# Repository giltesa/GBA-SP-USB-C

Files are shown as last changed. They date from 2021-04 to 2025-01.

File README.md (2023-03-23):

# Game Boy Advance SP USB-C & Audio Kit

This board allows to replace the original EXT2 connector and keep both original features: You can charge the GBASP by USB-C and **connect to your headphones to hear the games**!

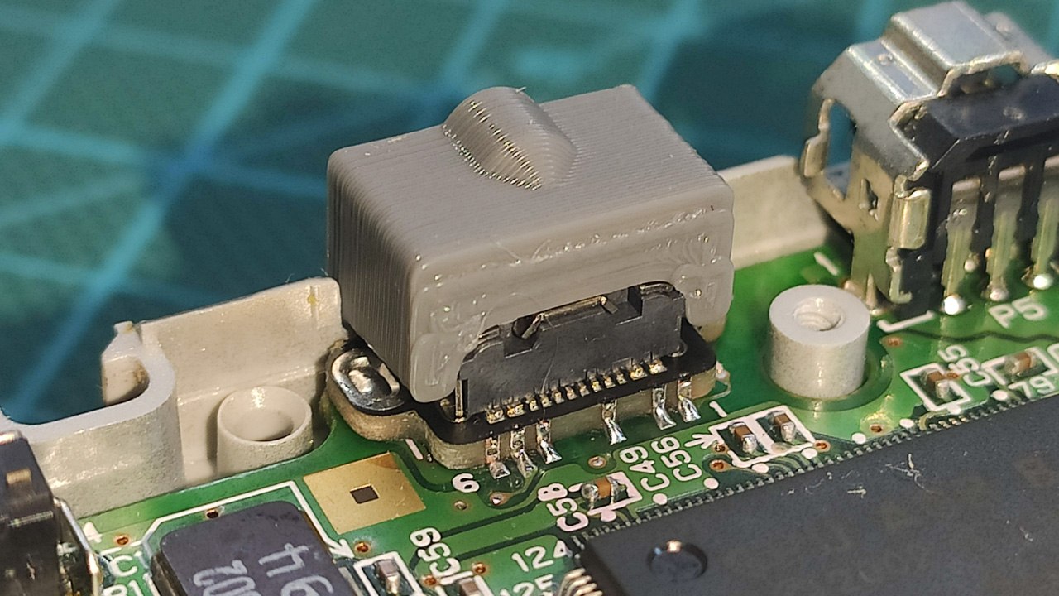
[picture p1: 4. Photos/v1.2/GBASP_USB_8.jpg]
GBASP

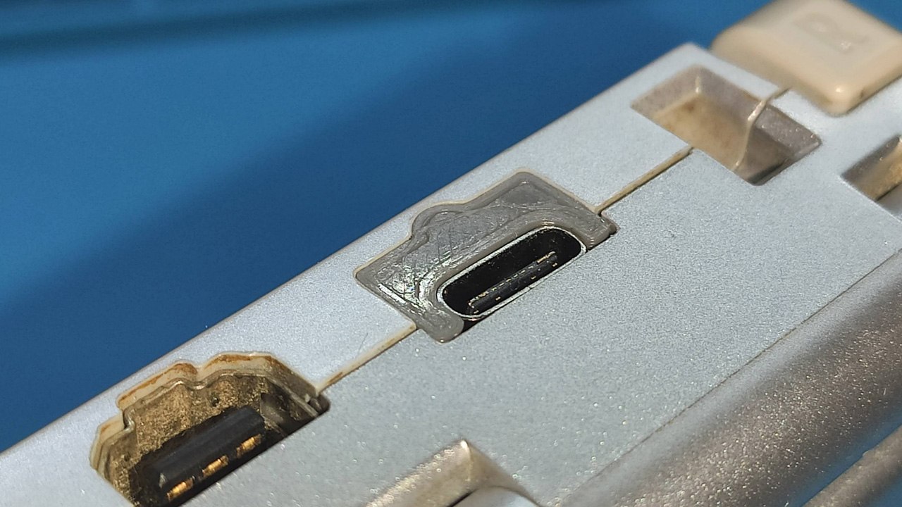
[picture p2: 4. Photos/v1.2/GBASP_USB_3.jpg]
GBASP

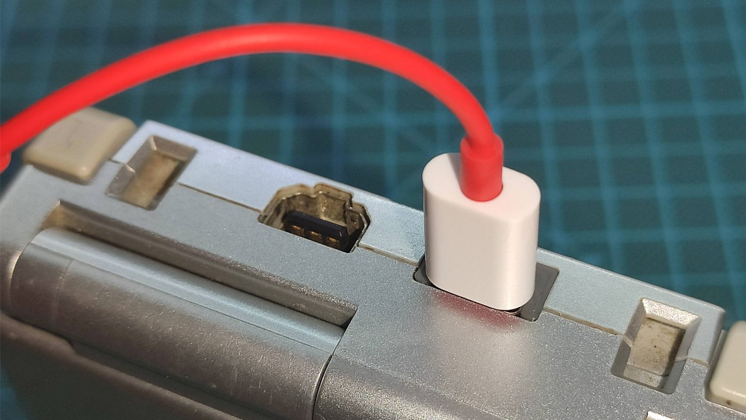
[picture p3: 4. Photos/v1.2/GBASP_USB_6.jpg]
GBASP


## Youtube:

Game Boy Advance SP USB-C & Audio Kit (Installation)

GBASP (https://www.youtube.com/watch?v=e_Pdkdgis8E)

## Would you like it?

https://shop.giltesa.com/product/game-boy-advance-sp-usb-c-kit/

https://shop.giltesa.com/product/game-boy-advance-sp-usb-c-kit-centered/

## More

- [giltesa.com](https://giltesa.com "giltesa.com")
- [twitter.com](https://twitter.com/giltesa/status/1503669454852481024 "twitter.com")

## Thanks

Thanks to these makers for publishing the information about the pinout and their experiences, it helped me to make this board:

[ishoug](https://www.youtube.com/watch?v=KATEinUUWz0 "ishoug")

[666Gothicgirl](https://www.youtube.com/watch?v=5_2sGFCsaPw "666Gothicgirl")

## License

This project is licensed under a **Creative Commons** license:
**[Attribution-NonCommercial-ShareAlike 4.0 International (CC BY-NC-SA 4.0) ](https://creativecommons.org/licenses/by-nc-sa/4.0/)**

Check the [LICENSE.md](LICENSE.md) for more information.

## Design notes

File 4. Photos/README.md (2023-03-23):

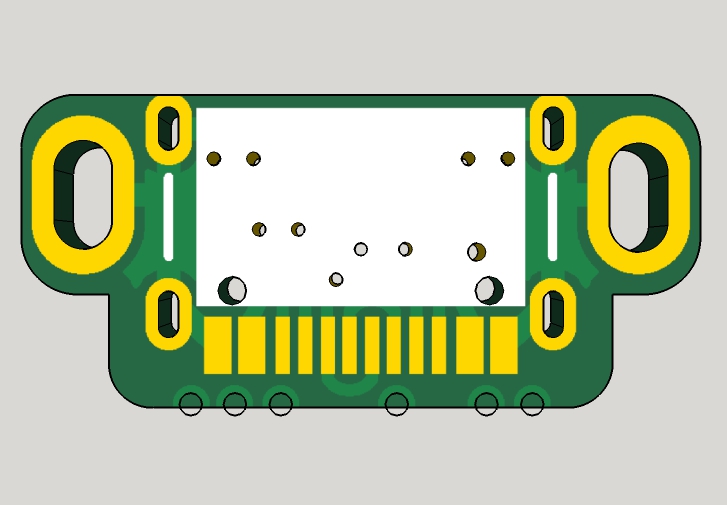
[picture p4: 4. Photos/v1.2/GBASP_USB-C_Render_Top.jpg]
GBASP

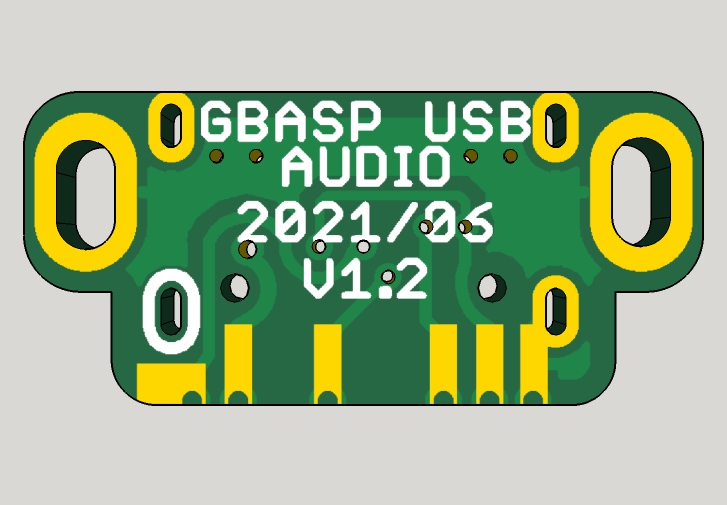
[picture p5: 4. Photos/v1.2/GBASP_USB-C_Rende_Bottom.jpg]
GBASP

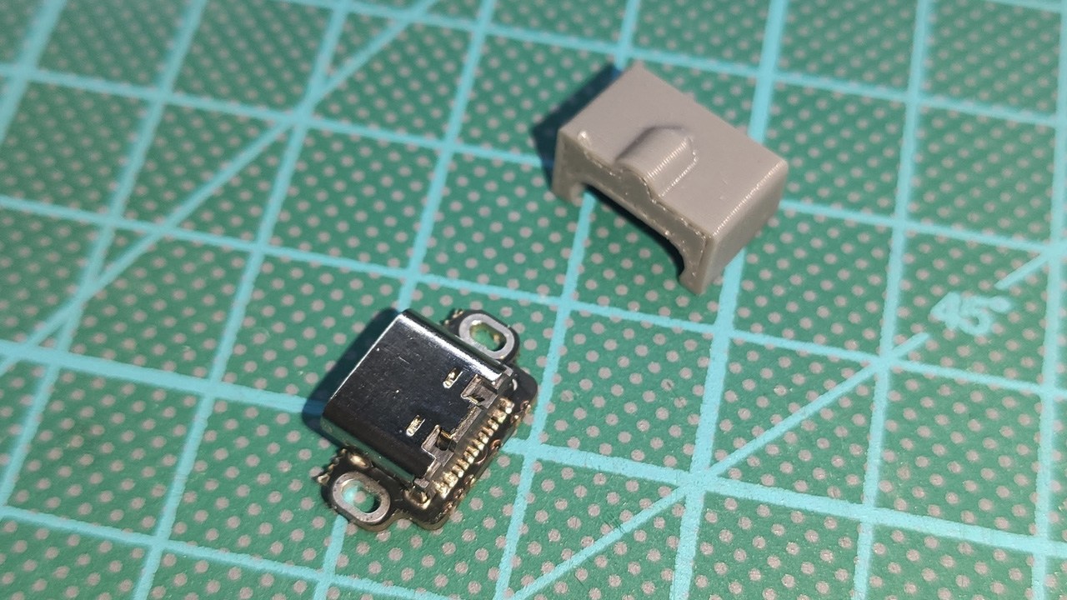
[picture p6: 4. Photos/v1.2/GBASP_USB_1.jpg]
GBASP

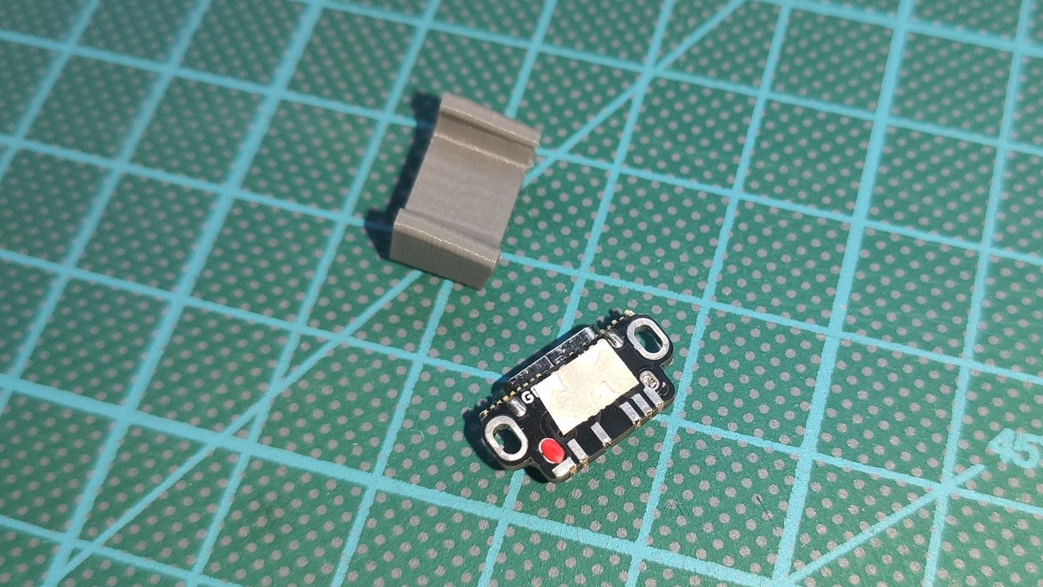
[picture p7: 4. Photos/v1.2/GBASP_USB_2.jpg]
GBASP

GBASP
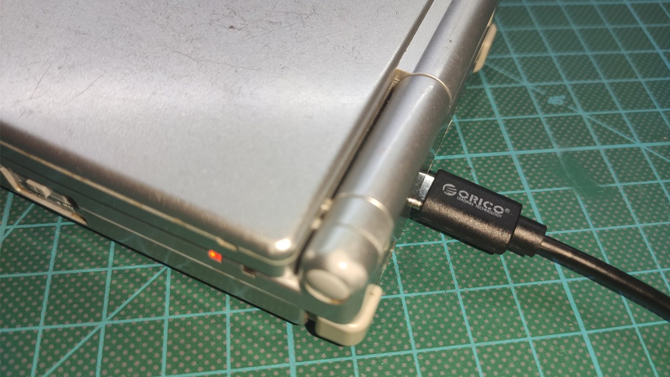
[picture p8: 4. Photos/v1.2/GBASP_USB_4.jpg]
GBASP

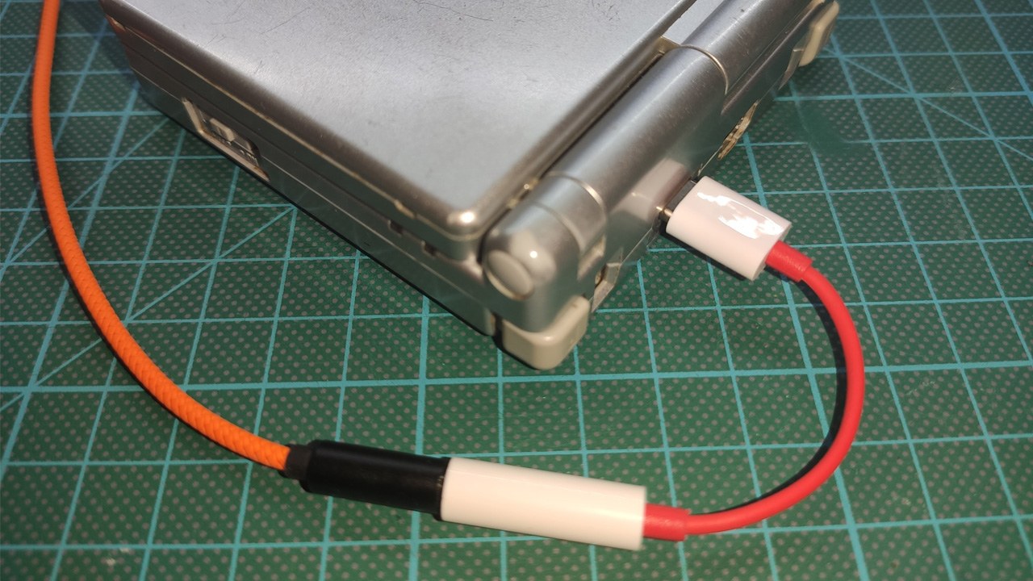
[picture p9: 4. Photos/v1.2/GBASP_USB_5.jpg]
GBASP

GBASP
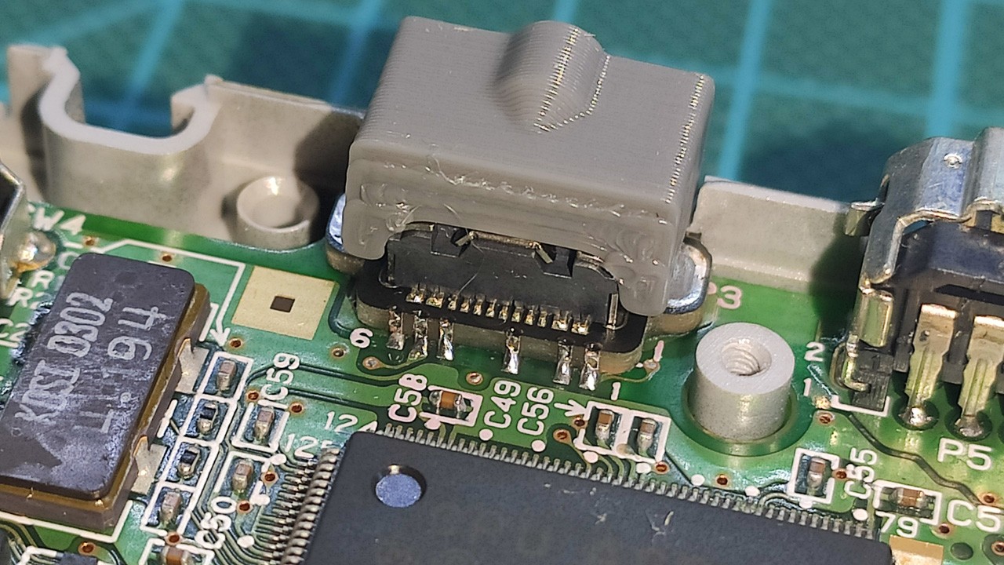
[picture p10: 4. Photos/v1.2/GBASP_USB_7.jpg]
GBASP

GBASP
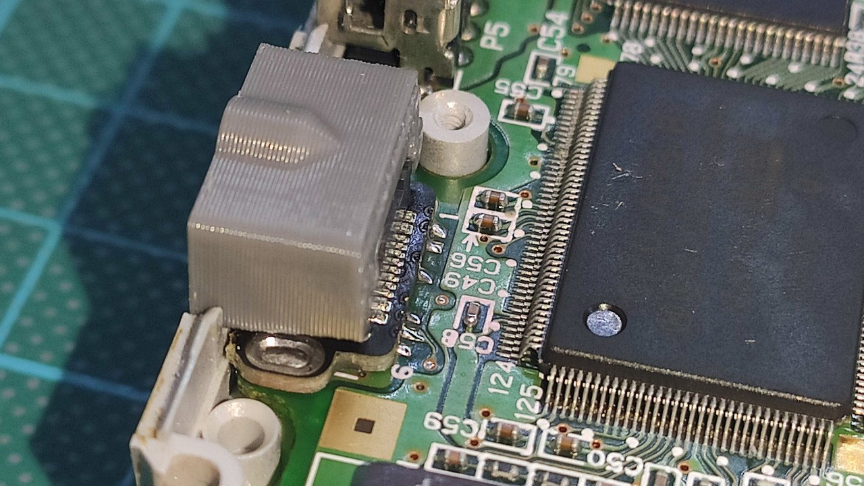
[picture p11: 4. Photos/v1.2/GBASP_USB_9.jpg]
GBASP


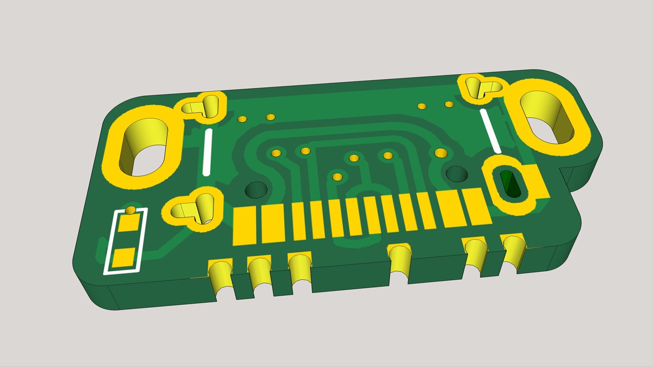
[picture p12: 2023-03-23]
2. Renders, 3D models/gbasp-v2.jpg

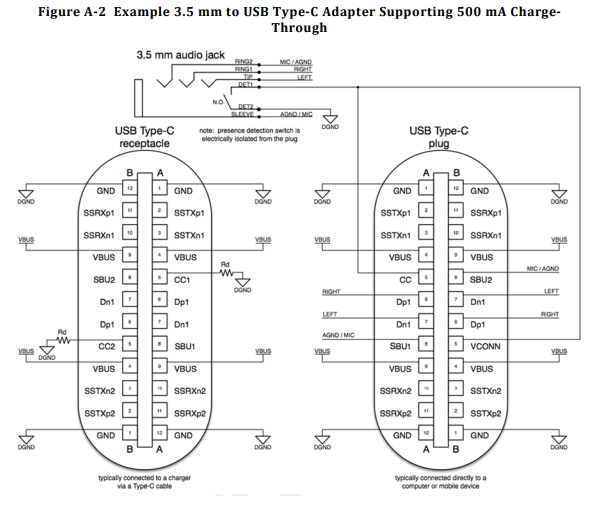
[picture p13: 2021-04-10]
3. Documentation/Datasheet/3mm-to-USB-Type-C-adapter-with-charging.png

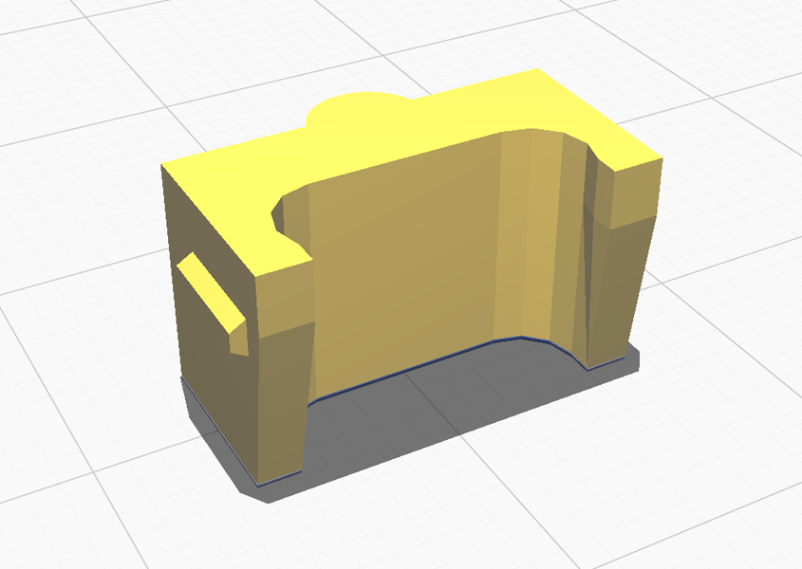
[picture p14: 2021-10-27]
2. Renders, 3D models/Plastic Cap/1. Half/v15/GBA-SP-CAP.png

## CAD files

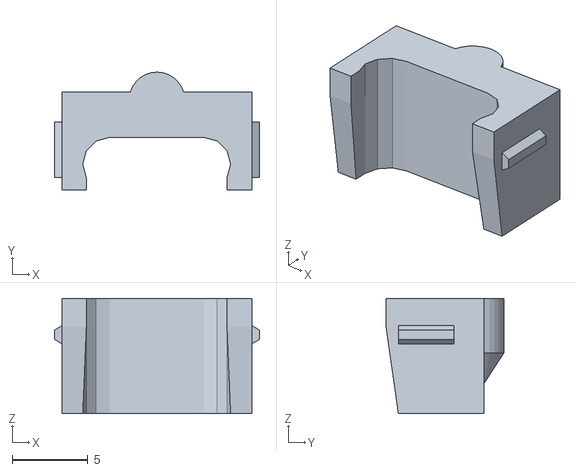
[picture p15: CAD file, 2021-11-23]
2. Renders, 3D models/Plastic Cap/1. Half/v15/GBA-SP-CAP.stl
13.5 x 7.76 x 7.60

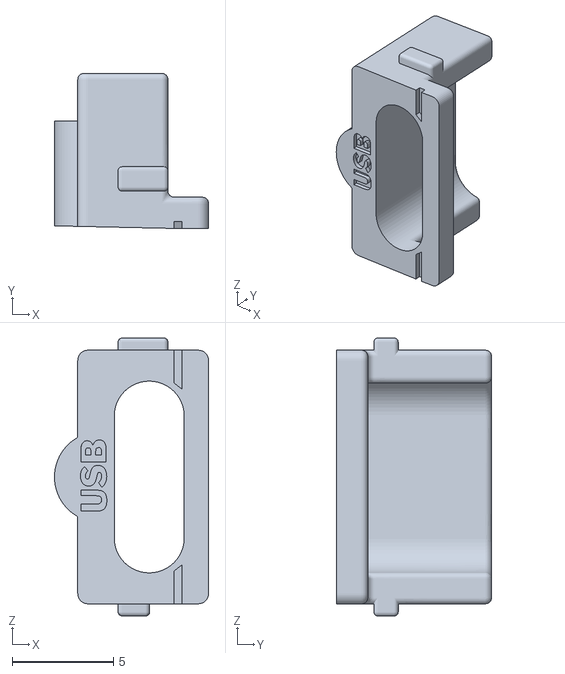
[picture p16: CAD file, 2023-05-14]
2. Renders, 3D models/Plastic Cap/2. Centered/v30/GBASP_CAP_v30.stl
7.60 x 7.65 x 13.7

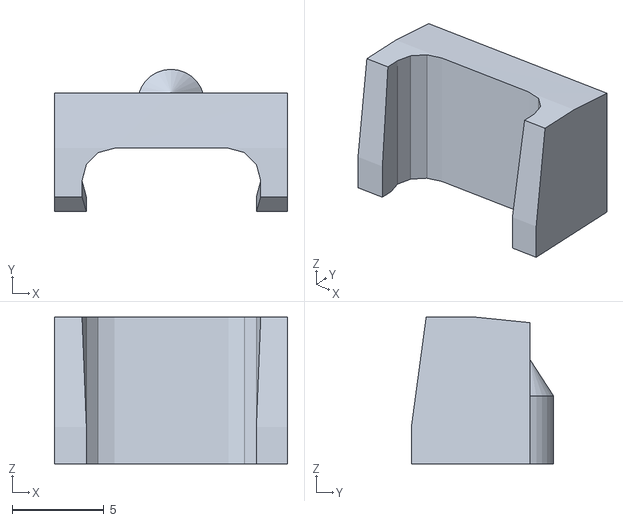
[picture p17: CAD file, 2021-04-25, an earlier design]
2. Renders, 3D models/Plastic Cap/1. Half/v13/GBA-SP-CAP.stl
12.7 x 7.76 x 8.00

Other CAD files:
2. Renders, 3D models/GBA SP 1.skp
2. Renders, 3D models/GBA SP 2.skp
2. Renders, 3D models/GBA-SP-CAP - Black.skp
2. Renders, 3D models/GBA-SP-CAP - Blue.skp
2. Renders, 3D models/Plastic Cap/1. Half/v13/GBA-SP-CAP.skp
2. Renders, 3D models/Plastic Cap/1. Half/v15/GBA-SP-CAP.skp
2. Renders, 3D models/Plastic Cap/2. Centered/v30/GBA-SP-CAP.skp
2. Renders, 3D models/Plastic Cap/2. Centered/v30/GBASP_CAP v30.f3d
2. Renders, 3D models/gbasp-v2.skp

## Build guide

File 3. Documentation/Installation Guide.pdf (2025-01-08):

# USB-C KIT For

# Game Boy Advance SP Nintendo DS

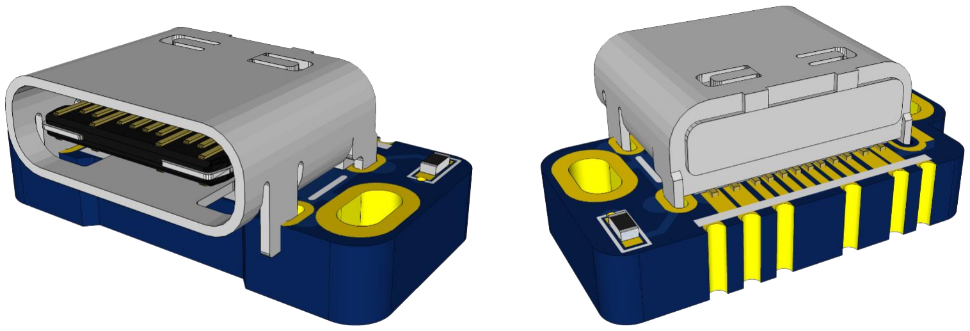
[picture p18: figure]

### PRODUCT v1.6+

HTTPS://SHOP.GILTESA.COM/PRODUCT/GAME-BOY-ADVANCE-SP-USB-C-KIT-CENTERED

# PLEASE READ THROUGH THESE INSTRUCTIONS

ENTIRELY BEFORE ATTEMPTING TO INSTALL.

# WARNING: IF YOU ARE NOT COMFORTABLE WITH SOLDERING, OR PERFORMING ANY STEP IN THIS

GUIDE, DO NOT PERFORM THE INSTALL YOURSELF.

# FIND SOMEONE WHO IS COMFORTABLE TO DO IT FOR

YOU.

INDEX

# Description

The Game Boy Advance SP: USB-C Kit allows to charge the battery by USB-C cable or connect headphones with USB-C or by jack adapter to USB-C in your Game Boy Advance SP (Also compatible with Nintendo DS, you can see some details of the installation at the end of the document.)
The USB-C specification has two ways of audio connections. Be sure your headphones or jack adapter use the first one because otherwise you will not be able to hear anything.
- COMPATIBLE: The legacy one that use some extra pines of the USB-C to take out the analog audio and where you can connect normal headphones or jack adapter.
- NOT COMPATIBLE: The advanced one where the headphones include a DAC (Digital to Analogue Converter) and needs energy from the USB connector to manage the electronic components inside the headphone’s connector.

There are two versions of this board, both with the same features except for the thickness of the board. The first one has 1.2mm thickness, and the USB-C connector is level with the joining of both parts of the GBASP shell. The second version has a 2.4mm thickness the USB-C connector is almost in the centre of the hole.

The plastic cap to cover the hole may change between both versions, check the shop product description for more details.

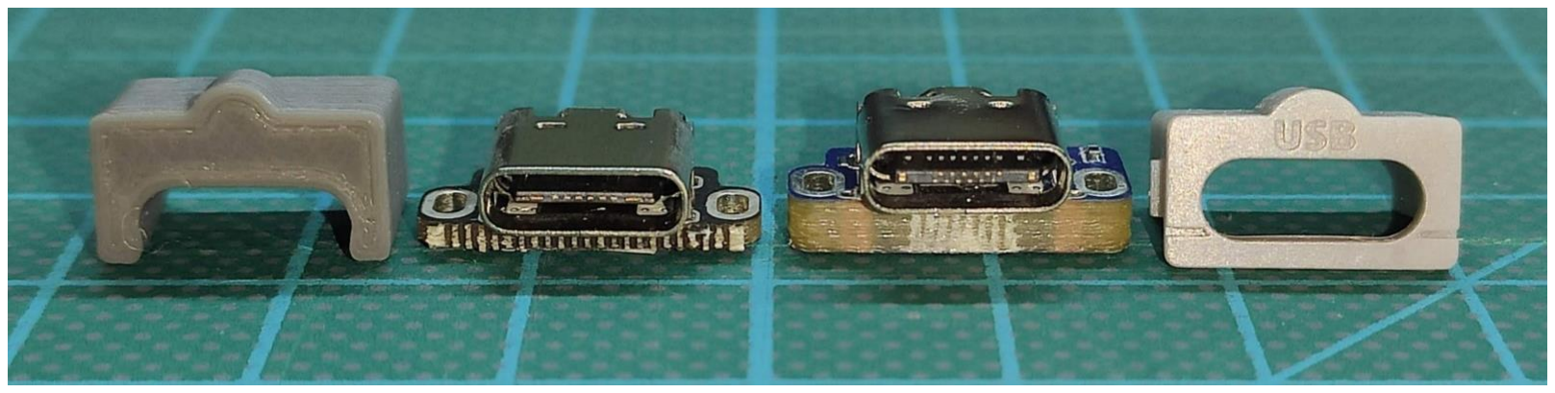
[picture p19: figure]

Comparison between the two versions: Left 1.2mm, right 2.4mm

# FEATURES

- New castellated holes (pads): It has never been so easy to solder it. (Link) (https://shop.giltesa.com/wp-content/uploads/2022/09/gbasp-usb-c-kit-installation.webp)
- Plastic cap made by 3D printer or resin 3D printer.
- Charging your Game Boy Advance SP by USB-C, compatible with:
- USB power banks
- USB-A chargers
- USB-C chargers *
- USB-C PD chargers (normal speed, not fast) *
- USB-A to USB-C cables
- USB-C to USB-C cables *
- Playing the sound using a USB-C headphones or USB-C adapter to Jack 3.5mm.

* This feature has been recently added but has a limitation. Before USB-C to USB-C cables were not compatible and they didn’t charge the GBA SP. They can be used now, but they work only connected in one side. It means when you connect the USB-C cable face up will charge correctly the battery and the orange led will turn on, but when you connect face down will not do anything.

(Supporting double side connecting disable the audio of the speaker. So, this is the best option to keep the audio works and makes the USB-C to USB-C cables/chargers compatible.

# INCLUDED

- 1 board (1.2mm or 2.4 mm thickness depending on the choose version)
- 1 plastic cap to cover the hole.

# Recommended / REQUIRED (NOT INCLUDED)

- Tri-wing and phillips screwdriver
- Tweezers
- Cutting plier
- Kapton tape
- Soldering iron
- Tin
- Flux
- Desoldering pump
- Desoldering mesh
- Isopropyl alcohol

# Board details

This tiny board has eight pads in about 1cm²
surface, which means it requires high soldering skills. The following explains what each pad is for.

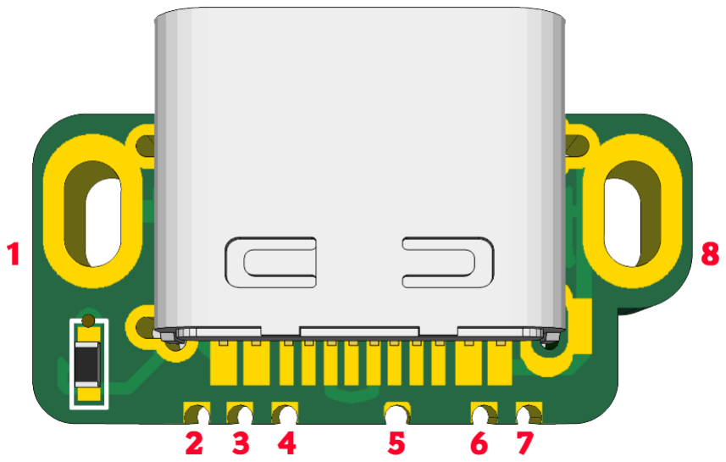
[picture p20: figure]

Starting from the left to the right:

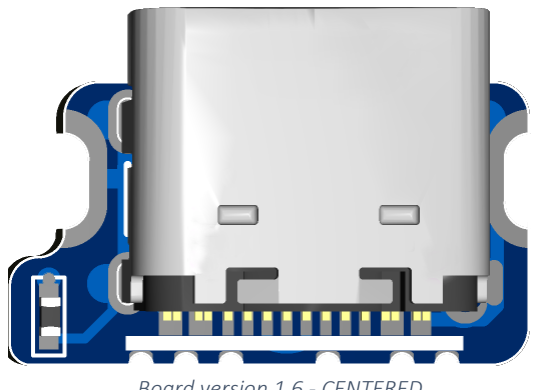
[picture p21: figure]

1. SHIELD *: | The shield pad, also as ground pad.
2. GND: | The ground pad.
3. SDN: | Shutdown pad to disable the speaker when the
| headphones are connected.
4. AUDIO GND: | The ground audio line.
5. AUDIO R: | The right audio line.
6. VCC: | The 5V line from the USB-C.
7. AUDIO L: | The left audio line.
8. SHIELD *: | The shield pad, also as ground pad.

* These two pads hold the board to the GBA SP motherboard, make sure to solder them well to hold the board properly.

2023-01: v1.6: The pads 1 and 8, called SHIELD, have been modified to facilitate installation. Now it is much easier to install, and since soldering can be done more easily, it is more robust, as previously, when these pads were closed, the soldering could be incorrectly applied.

Board version 1.6 - CENTERED

# INSTALLATION STEPS

## Pre installation Steps

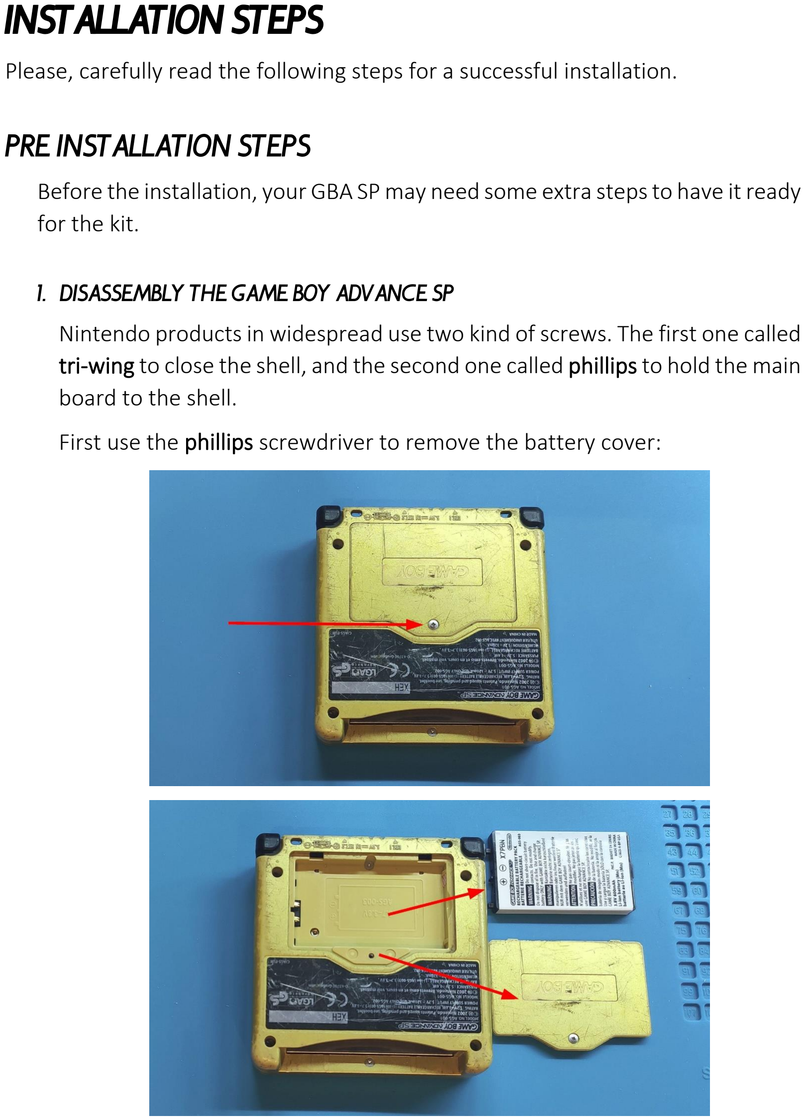
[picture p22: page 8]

Please, carefully read the following steps for a successful installation.

Before the installation, your GBA SP may need some extra steps to have it ready for the kit.

1. Disassembly the Game Boy ADVANCE SP

Nintendo products in widespread use two kind of screws. The first one called tri-wing to close the shell, and the second one called phillips to hold the main board to the shell.

First use the phillips screwdriver to remove the battery cover:

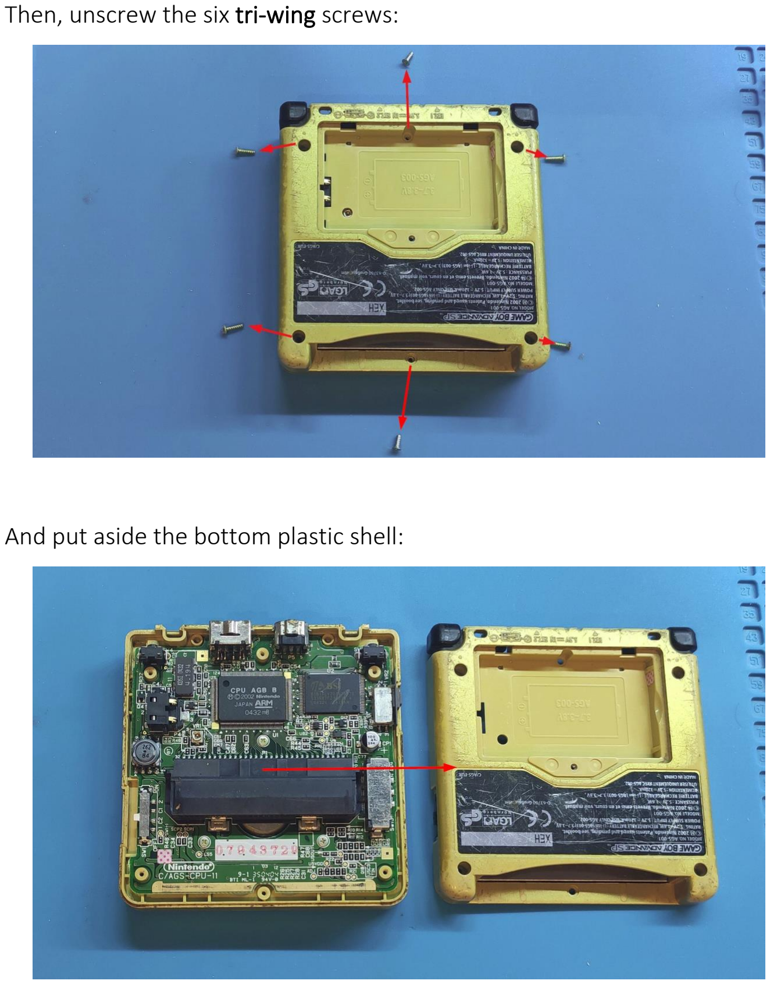
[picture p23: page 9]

Then, unscrew the six tri-wing screws:

And put aside the bottom plastic shell:

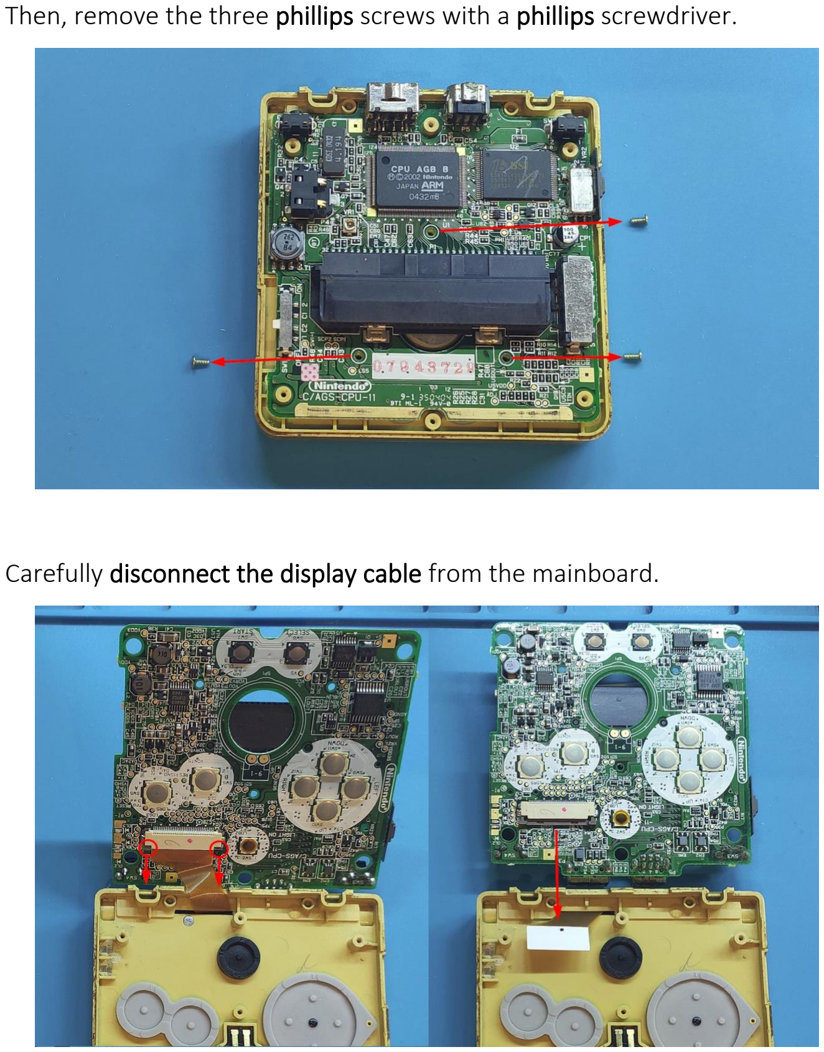
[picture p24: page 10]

Then, remove the three phillips screws with a phillips screwdriver.

Carefully disconnect the display cable from the mainboard.

As last step, the volume switch cover can be removed, but do not force it as it may be held tightly.

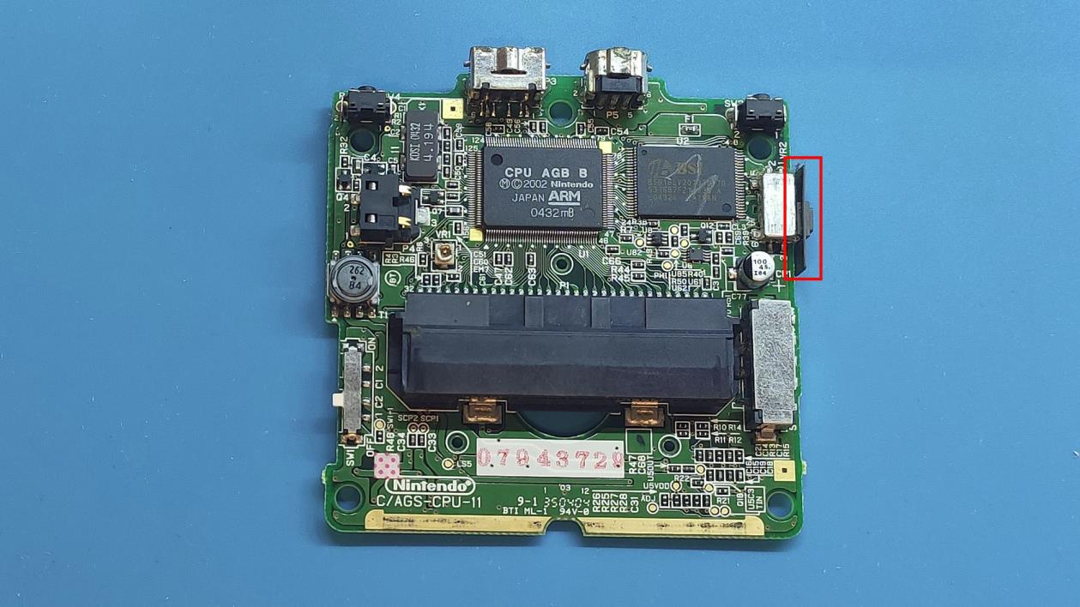
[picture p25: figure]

2. Cleaning the mainboard

Use isopropyl alcohol to clean the board. Since the board was made in 2002, the board may be full of dust. All this dirt can be cleaned with alcohol.

## installation Steps

1. Protect the nearest components

Use Kapton tape to protect and avoid any damage to the electronic components that are next to the connector.

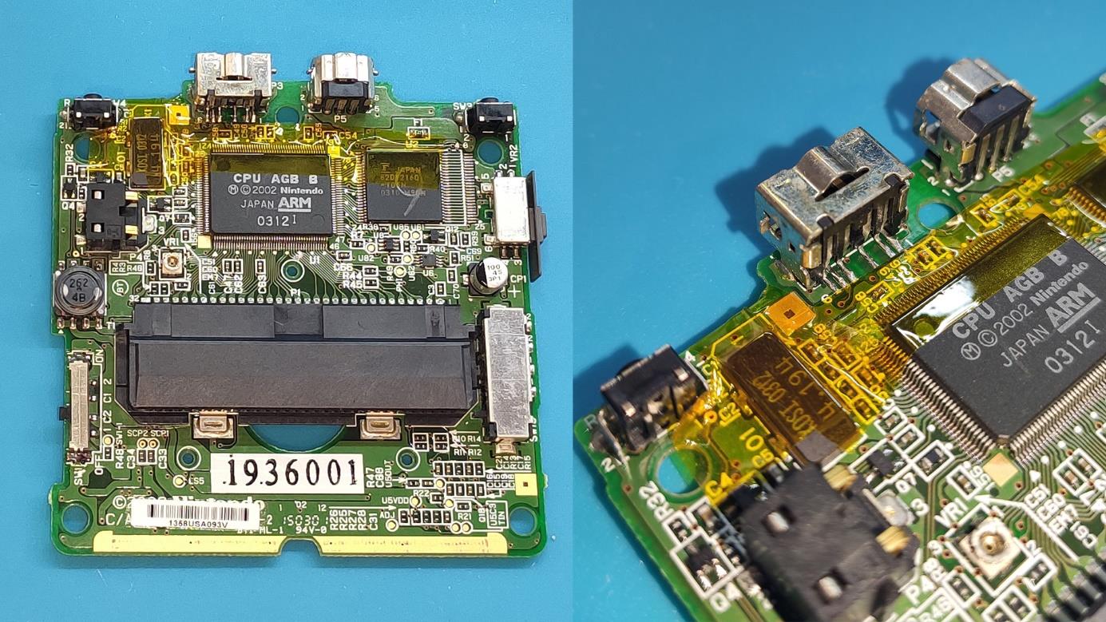
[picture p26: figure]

2. Remove unnecessary components

This kit only requires removing the EXT.2 connector. However, it has many legs, and it may be hard to remove. Following the next steps should help to do it.

If you have an air solder station, you can remove it easily, but protect perfect the nearest places with Kapton tape or something may be burn.

Otherwise, the recommendation is using a desoldering pump which will help to remove the tin from the shield pads.

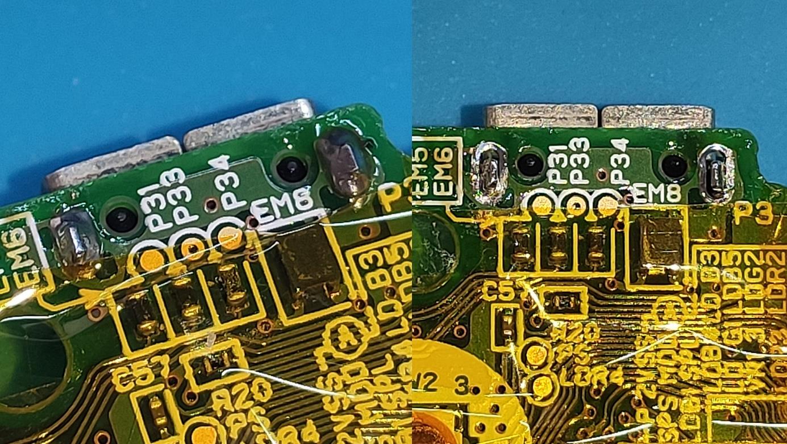
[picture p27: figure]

Left before, right after
After that, with the solder iron is possible to heat the remaining six legs at the same time and remove the connector. Some flux will help to desolder it.

BE INCREDIBLY CAREFUL WHEN REMOVING THE CONNECTOR. THE COPPER PADS, WHERE THE CONNECTOR IS SOLDERED, ARE EXTREMELY FRAGILE AND CAN PEEL OFF.

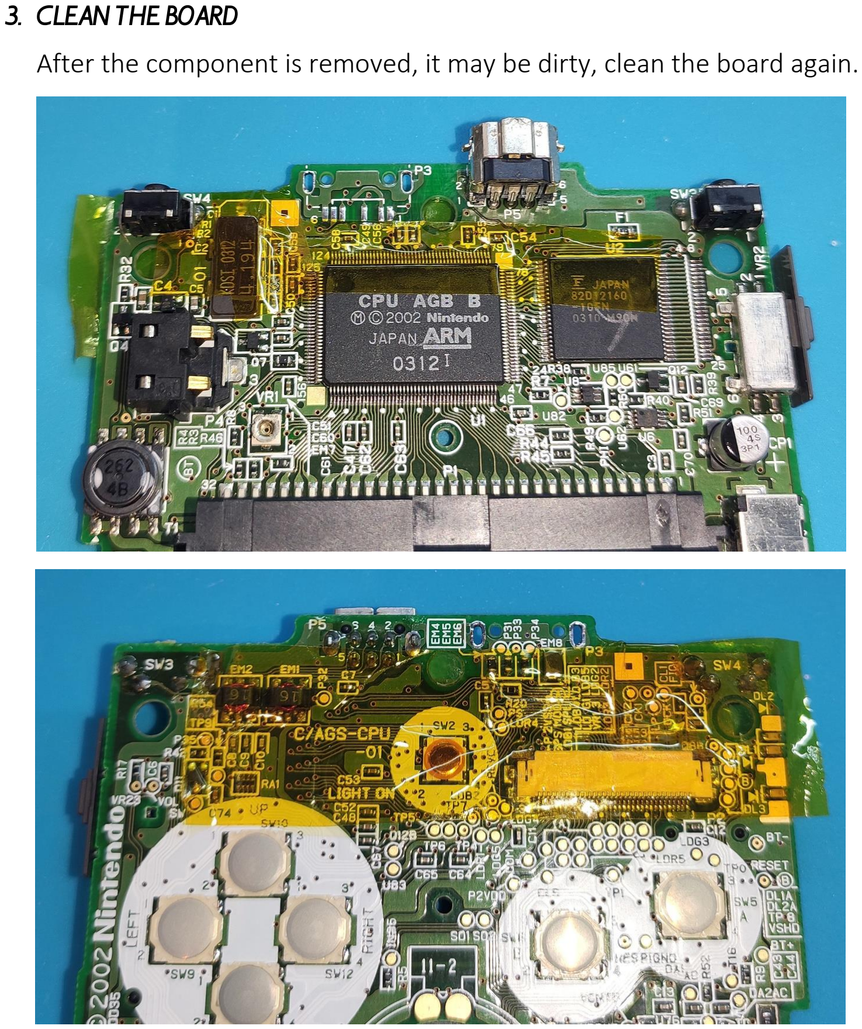
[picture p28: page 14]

3. Clean the board

After the component is removed, it may be dirty, clean the board again.

4. Installation of the USB-C board

The easier way to centre the board on the mainboard is when the mainboard is screw on the GBA SP shell, so, you can put it back (the video cable doesn’t need to be connected)

Once the mainboard is in the shell, you can place the board on the place where the original connector was. The board also must be touching the back of the plastic shell.

Please, see below video to understand how to do it:

https://www.youtube.com/watch?v=PKm9SWTC8MQ

At this point, you can put the plastic lid and check everything matches correctly.

After the 6 pads are correctly soldered, remove the mainboard from the plastic shell and finish the installation soldering the 2 big pads that will hold strong the board to the mainboard.

Be sure you solder it well and both pads are joined with the tin, otherwise the connector may move and damage the 6 weak pads.

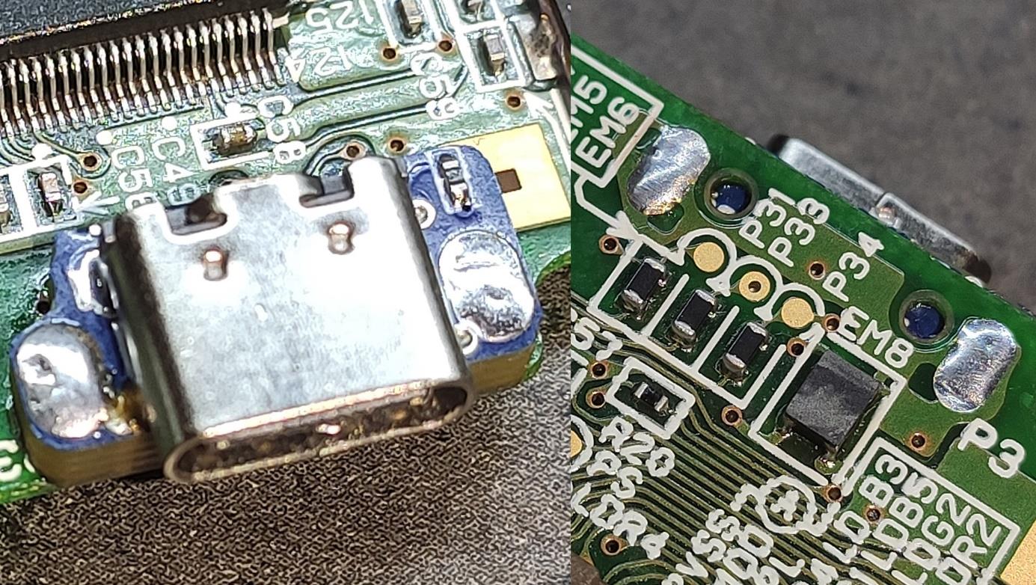
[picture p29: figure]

5. Finishing the installation

Now, you can put the mainboard back to the shell, connect the video cable, put the screws and everything as before. Enjoy it!

https://www.youtube.com/watch?v=ZznNsDhFl9U

6. Alternative PADS for soldering

If during the removal of the original connector any pads were broken, you can solder the board to the following alternative pins:

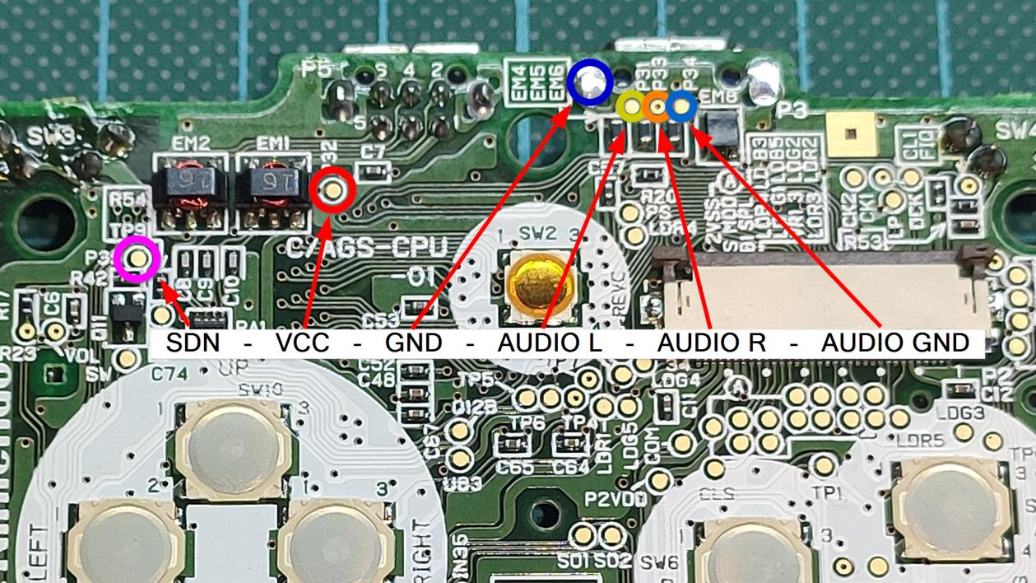
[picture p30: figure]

Installation on Nintendo DS.

The installation on this console is very similar to the GBA SP, although it requires a couple of modifications to the plastic cap and the rear casing of the console.

Once again: open the console, disconnect the 4 flat cables and the antenna cable, remove the motherboard from the casing, and desolder the original charging and audio connector (in case you didn’t know, in addition to the audio jack, this connector can also be used as an audio output, but without a microphone input).

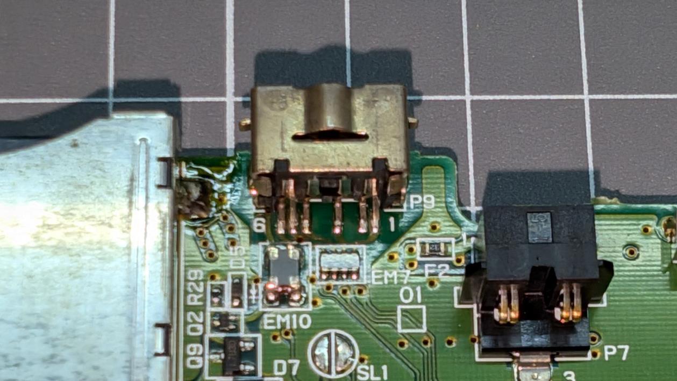
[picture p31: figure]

After removing the connector, you can install the new one. Be careful not to let it protrude too much so that it doesn't interfere with the lower casing. To do it correctly, it will help to place the motherboard back into the casing, and with the USB-C connector in its position, solder the first pin. Then, remove the motherboard again and solder all the remaining pins.

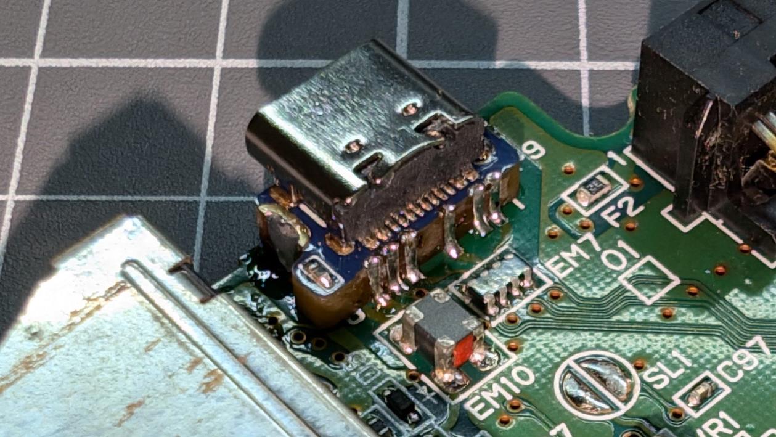
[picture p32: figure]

As for the modifications mentioned earlier, it's necessary to trim the side fins of the plastic cap because they are too wide and won't fit properly. Ideally, the width should be reduced, but the plastic is very brittle under pressure, so it's better to remove them completely.

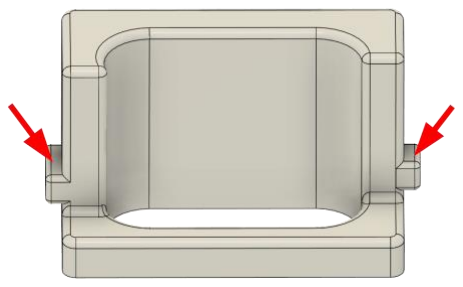
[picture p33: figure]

You will also need to remove some plastic from this area.

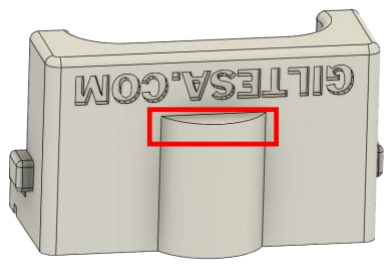
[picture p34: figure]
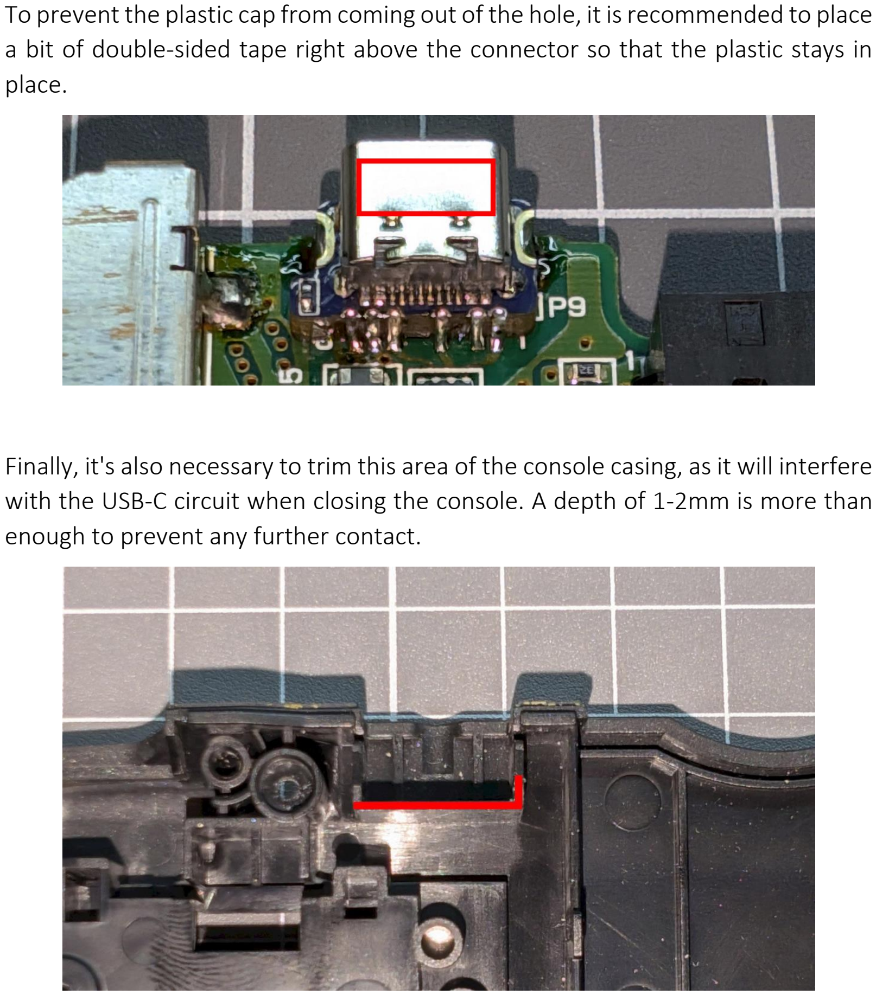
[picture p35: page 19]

To prevent the plastic cap from coming out of the hole, it is recommended to place a bit of double-sided tape right above the connector so that the plastic stays in place.

Finally, it's also necessary to trim this area of the console casing, as it will interfere with the USB-C circuit when closing the console. A depth of 1-2mm is more than enough to prevent any further contact.

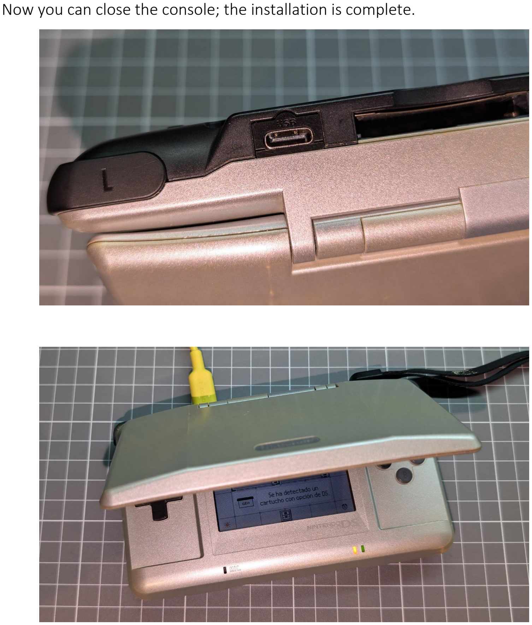
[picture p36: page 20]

Now you can close the console; the installation is complete.

# Frequently Asked Questions - FAQ

1. The console doesn't charge with USB-C to USB-C cables/chargers.
All our kits incorporate two resistors to indicate to the charger that it is a legacy device and should charge at a maximum of 5V.

The only reason it might not work is that you might be using a charger/cable from Apple or another company that doesn’t fully adhere to the standard, or perhaps it has an internal microchip to verify that the cable is original, which interferes with the console's normal charging. Trying other cables, such as those from a Nintendo Switch, a laptop, or another mobile device, should work.

2. The speaker is not working.
Make sure you haven’t created a short circuit between pins 2 and 3 (GND and SDN, respectively). If you can’t see it visually, use a multimeter in continuity mode to check.
3. The console DOESN’T turn on.
Make sure all the cables are properly connected and, most importantly, that the battery is in good condition. I'm not entirely sure about the GBA SP, but on the Nintendo DS, the orange LED that indicates charging blinks if the battery cannot charge due to being in poor condition. The normal behavior is for the LED to stay on continuously until charging is complete, at which point it turns off.

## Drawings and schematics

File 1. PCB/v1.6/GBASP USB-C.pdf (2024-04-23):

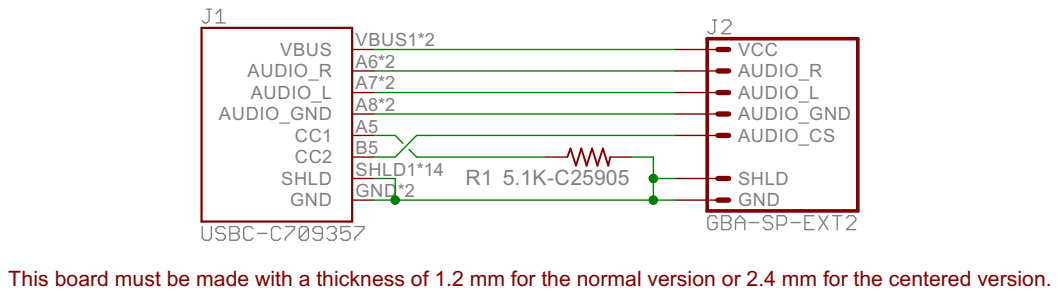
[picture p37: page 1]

This board must be made with a thickness of 1.2 mm for the normal version or 2.4 mm for the centered version.

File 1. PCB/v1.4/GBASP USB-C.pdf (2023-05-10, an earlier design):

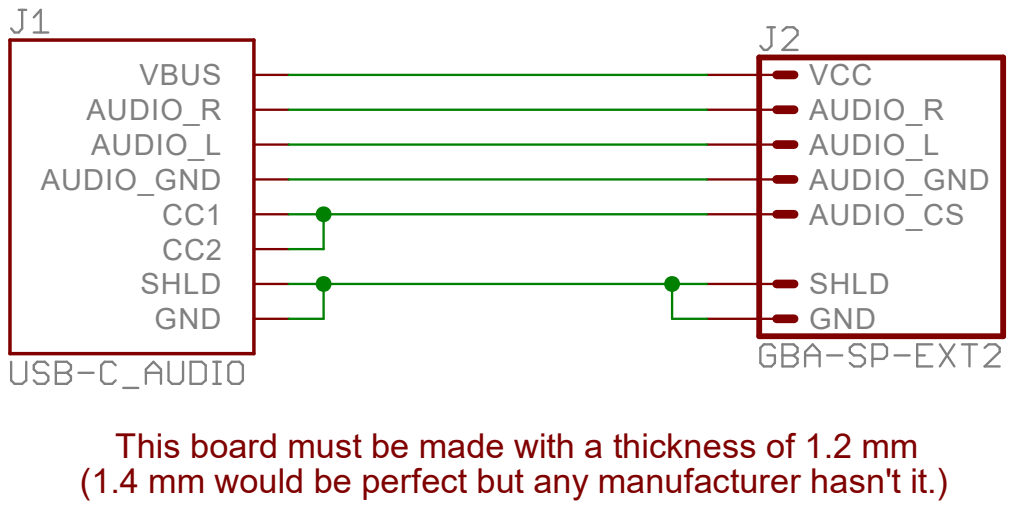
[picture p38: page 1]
AUDIO_GND AUDIO_CS; AUDIO_R AUDIO_L; VCC; GND; SHLD; VBUS; CC1 CC2 SHLD; AUDIO_R AUDIO_L AUDIO_GND

This board must be made with a thickness of 1.2 mm
(1.4 mm would be perfect but any manufacturer hasn't it.)

GBA SP USB-C
http://giltesa.com

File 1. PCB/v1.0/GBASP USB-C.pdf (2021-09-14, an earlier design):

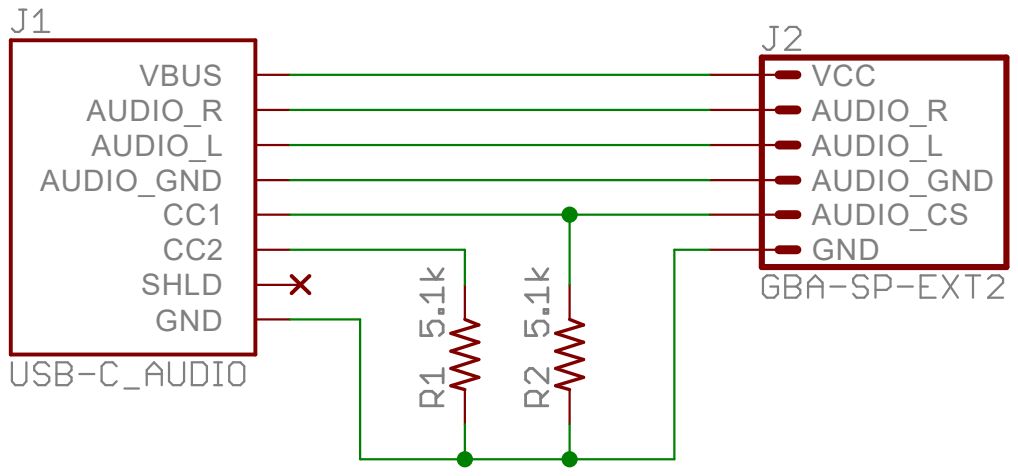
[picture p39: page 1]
AUDIO_GND AUDIO_CS; AUDIO_R AUDIO_L; VCC; GND; VBUS; CC1 CC2 SHLD; AUDIO_R AUDIO_L AUDIO_GND

GBP SP USB-C
http://giltesa.com

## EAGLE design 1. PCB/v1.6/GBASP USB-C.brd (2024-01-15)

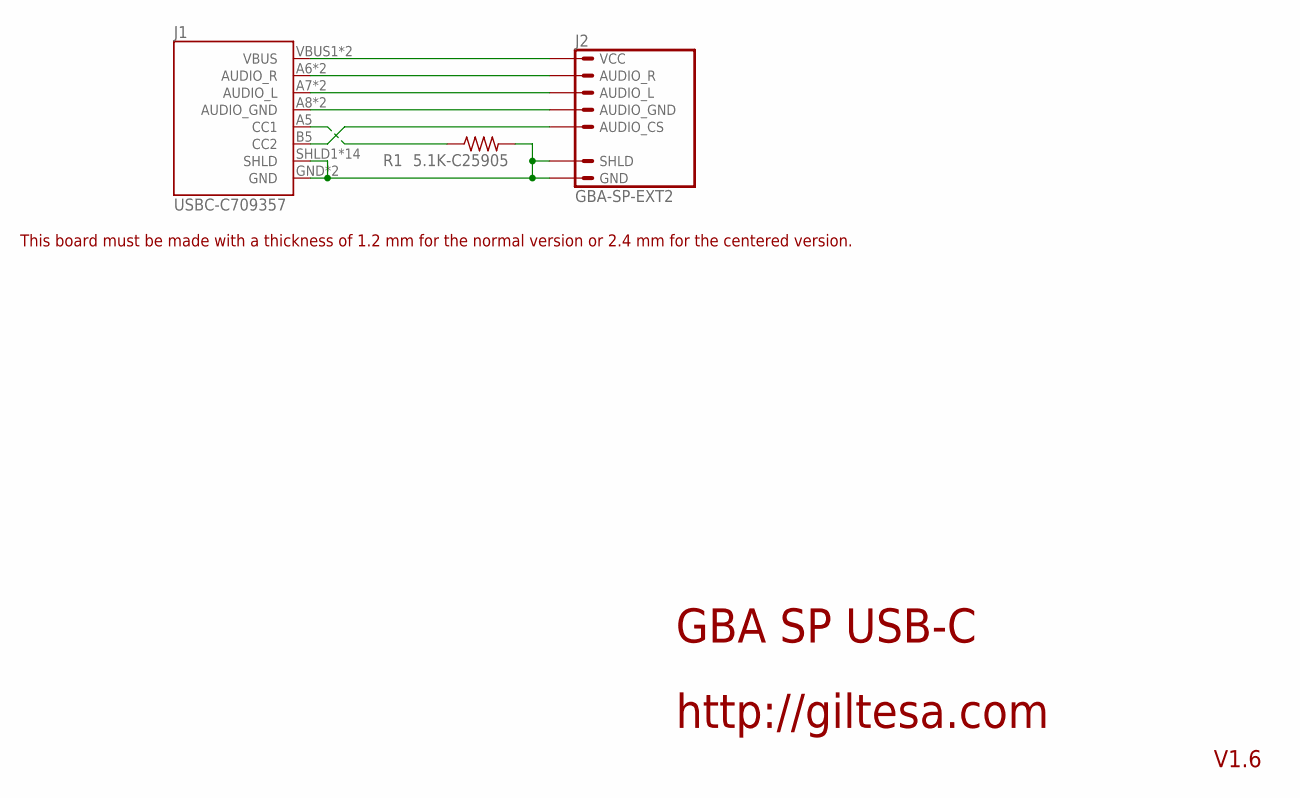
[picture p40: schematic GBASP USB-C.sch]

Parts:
J1: USBC-C709357; USB-C_16P_3SHLD_DRILL
J2: GBA-SP-EXT2; GBA-SP-EXT2_1
R1: 5.1K-C25905; R0402

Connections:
AUDIO_GND: J1.A8 (AUDIO_GND), J1.B8 (AUDIO_GND), J2.AUDIO_GND
AUDIO_L: J1.A7 (AUDIO_L), J1.B7 (AUDIO_L), J2.AUDIO_L
AUDIO_R: J1.A6 (AUDIO_R), J1.B6 (AUDIO_R), J2.AUDIO_R
CC2: J1.B5 (CC2), J2.AUDIO_CS
GND: J1.GND, J1.GND2 (GND), J1.SHLD1 (SHLD), J1.SHLD1_2 (SHLD), J1.SHLD3 (SHLD), J1.SHLD3_2 (SHLD), J1.SHLD4 (SHLD), J1.SHLD4_2 (SHLD), J1.SHLD5 (SHLD), J1.SHLD5_2 (SHLD), J1.SHLD6 (SHLD), J1.SHLD6_2 (SHLD), J1.SHLD7 (SHLD), J1.SHLD7_2 (SHLD), J1.SHLD8 (SHLD), J1.SHLD8_2 (SHLD), J2.GND, J2.SHLD1 (SHLD), J2.SHLD2 (SHLD), J2.SHLD3 (SHLD), J2.SHLD4 (SHLD), R1.2
unnamed: J1.A5 (CC1), R1.1
VCC: J1.VBUS1 (VBUS), J1.VBUS2 (VBUS), J2.VCC

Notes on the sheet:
GBA SP USB-C
http://giltesa.com
V1.6
This board must be made with a thickness of 1.2 mm for the normal version or 2.4 mm for the centered version.

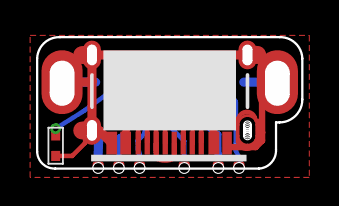
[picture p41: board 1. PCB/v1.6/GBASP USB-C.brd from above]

Board: 2 copper layers, 14.7 x 7.3 mm, 3 parts (0 on the bottom side), 7 nets.

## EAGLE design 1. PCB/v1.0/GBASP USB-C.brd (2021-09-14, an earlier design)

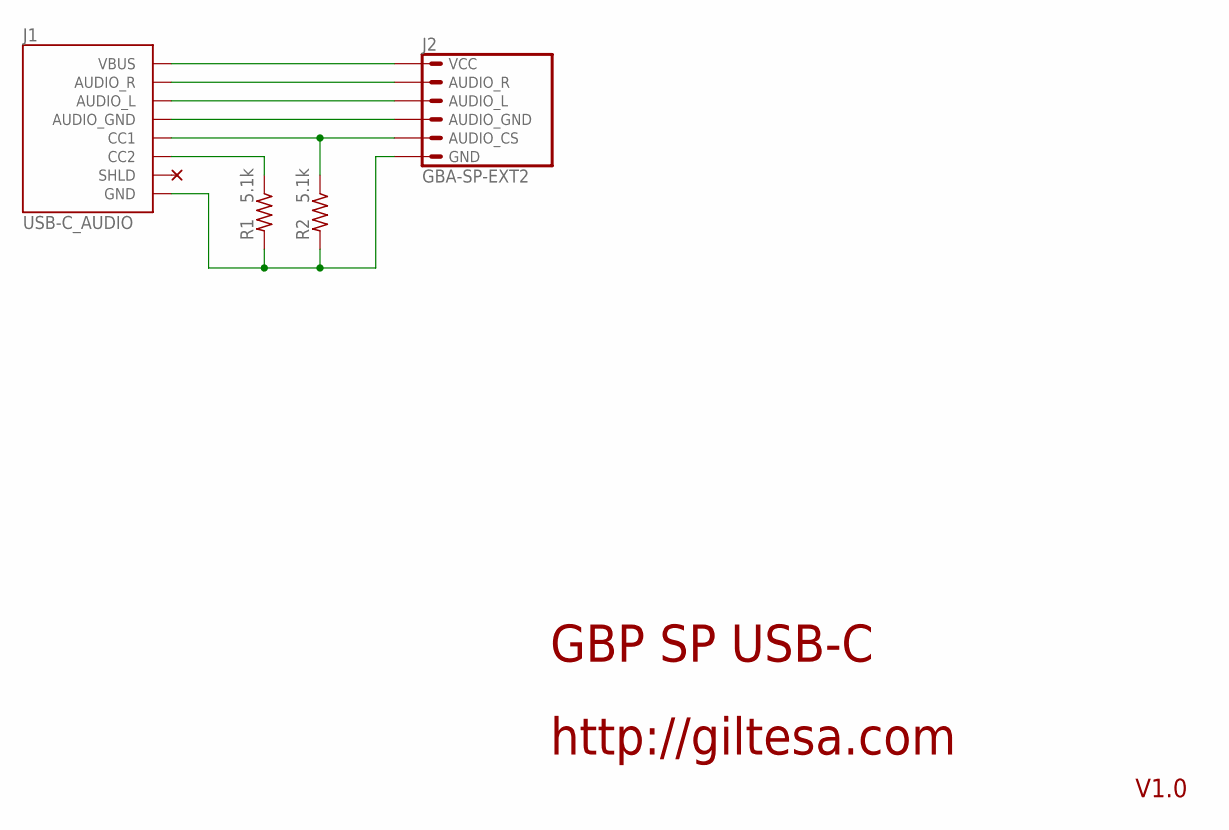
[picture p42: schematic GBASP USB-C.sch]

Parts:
J1: USB-C_AUDIO; USB-C_16P_SHLD2
J2: GBA-SP-EXT2
R1, R2: 5.1k; R0402

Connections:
AUDIO_GND: J1.A8 (AUDIO_GND), J1.B8 (AUDIO_GND), J2.AUDIO_GND@1 (AUDIO_GND), J2.AUDIO_GND@2 (AUDIO_GND)
AUDIO_L: J1.A7 (AUDIO_L), J1.B7 (AUDIO_L), J2.AUDIO_L@1 (AUDIO_L), J2.AUDIO_L@2 (AUDIO_L)
AUDIO_R: J1.A6 (AUDIO_R), J1.B6 (AUDIO_R), J2.AUDIO_R@1 (AUDIO_R), J2.AUDIO_R@2 (AUDIO_R)
CC1: J1.A5 (CC1), J2.AUDIO_CS@1 (AUDIO_CS), J2.AUDIO_CS@2 (AUDIO_CS), R2.1
CC2: J1.B5 (CC2), R1.1
GND: J1.GND, J1.GND2 (GND), J2.GND@1 (GND), J2.GND@2 (GND), R1.2, R2.2
VCC: J1.VBUS1 (VBUS), J1.VBUS2 (VBUS), J2.VCC@1 (VCC), J2.VCC@2 (VCC)

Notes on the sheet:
GBP SP USB-C
http://giltesa.com
V1.0

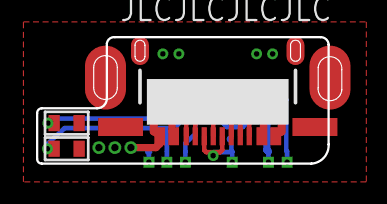
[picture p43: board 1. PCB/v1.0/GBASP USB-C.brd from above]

Board: 2 copper layers, 16.9 x 7.0 mm, 4 parts (0 on the bottom side), 7 nets.
